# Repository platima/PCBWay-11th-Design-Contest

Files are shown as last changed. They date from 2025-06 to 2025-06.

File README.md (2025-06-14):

# Innovation Lightbulb Badge - Touch-Activated RGB LEDs

**🏆 My entry for the PCBWay 11th Design Contest:** *"11 Years of Innovation and Beyond with PCBWay"*


## Table of Contents
- [Overview](#overview)
- [Features](#-features)
- [Hardware Requirements](#-hardware-requirements)
- [Getting Started](#-getting-started)
  - [Prerequisites](#prerequisites)
  - [Assembly Instructions](#assembly-instructions)
  - [Programming Setup](#programming-setup)
  - [Installation](#installation)
- [How It Works](#-how-it-works)
- [Configuration](#️-configuration)
- [PCB Design](#-pcb-design)
- [Performance](#-performance)
- [Troubleshooting](#️-troubleshooting)
- [Animation Modes](#-animation-modes)
- [Power Management](#-power-management)
- [Future Enhancements](#-future-enhancements)
- [Version History](#-version-history)
- [Contributing](#-contributing)
- [License](#-license)
- [Acknowledgments](#-acknowledgments)
- [Contact](#-contact)

## Overview

A creative lightbulb-shaped badge featuring touch-activated LED animations, combining PCB art with functional electronics. The badge celebrates PCBWay's 11-year journey with an interactive cog/gear LED pattern that comes to life when you touch the golden snake base.

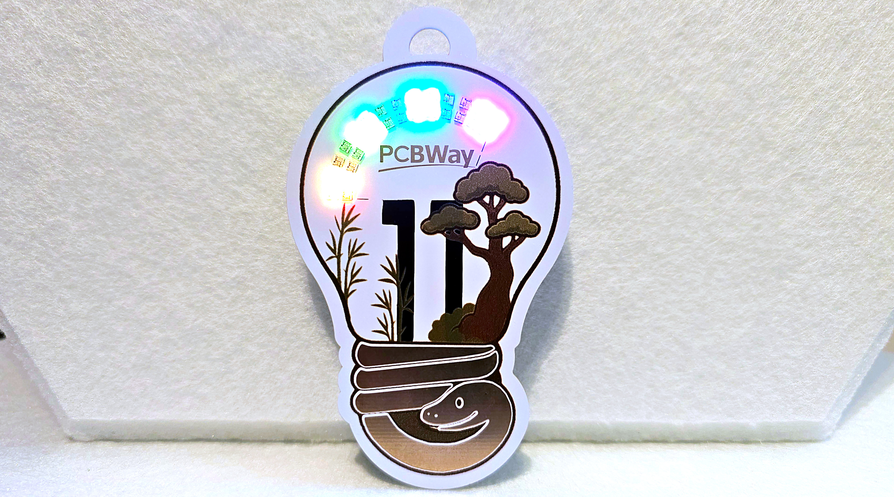
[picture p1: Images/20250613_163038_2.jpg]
Innovation Lightbulb Badge


*The completed Innovation Lightbulb Badge showcasing PCBWay's precision manufacturing. [Animation video here](https://youtu.be/jnBDUs-5CoI)*

## 🌟 Features

- **Touch Activation**: 28 cog/gear LEDs illuminate when touching the golden snake base
- **Multiple Animation Modes**: 5 different color patterns including rainbow, PCBWay green, fortune red, Australian colors, and white
- **Rotating Animation**: LED pattern simulates a turning gear/cog mechanism with configurable speed
- **Cultural Integration**: Year of the Wood Snake (2025) with bamboo and Chinese pine tree artwork
- **PCB Art**: Complex lightbulb cutout showcasing PCBWay's precision manufacturing and UV print capabilities
- **Low Power Design**: Battery-efficient with automatic sleep mode when not in use
- **Mode Cycling**: Automatically cycles through different color themes every 10 seconds of use
- **Interactive Badge**: Encourages human connection and conversation
- **Open Source**: Full KiCad files, firmware, and documentation shared with the maker community

## 🔧 Hardware Requirements

### Main Components
- **PCB**: Custom lightbulb-shaped design (order from PCBWay)
- **Microcontroller**: STM8S003F3P6 (20-pin TSSOP package)
- **LEDs**: 28x WS2812B addressable RGB LEDs (32 configured in firmware for animation wrapping)
- **Power**: LiPo battery (recommended: 503035 or 602535 with protection circuit)
- **Touch Sensor**: Golden snake pads (built into PCB design)

### Additional Components
See [/Hardware/BOM.csv](/Hardware/BOM.csv) for complete bill of materials including:
- Voltage regulators and power management ICs
- Capacitors and resistors
- Battery charging circuit components
- Programming header components

### Tools Required
- **Programming**: ST-Link v2 programmer (or compatible)
- **Soldering**: Hot air rework station, solder paste, flux
- **Assembly**: Fine-tip tweezers, magnifying glass
- **Power**: 3.3-5V power supply or LiPo battery

## 🚀 Getting Started

### Prerequisites

#### Software Requirements
- **Arduino IDE 2.0** or later
- **STM8 Arduino Core**: Add `https://github.com/akashkapashia/stm8_arduino/raw/master/package_sduino_stm8_index.json` to Board Manager URLs
- **ST-Link Drivers**: Install ST-Link v2 drivers for your operating system

#### Hardware Requirements
- ST-Link v2 programmer
- 4-wire connection: RST, GND, SWIM, 5V
- Power source (battery or bench supply)

### Assembly Instructions

#### Ordering PCB from PCBWay

##### Option 1 - KiCad Plugin (Recommended)
1. Download the complete `/Hardware/KiCad Files/` folder
2. Open `PCBWay_11th_Design_Contest.kicad_pro` in KiCad 9 or later
3. Use the PCBWay plugin to order directly from KiCad
4. Select UV printing option for the artwork layers

##### Option 2 - Manual Gerber Upload
1. Visit [PCBWay.com](https://www.pcbway.com)
2. Upload [/Hardware/Gerbers.zip](/Hardware/Gerbers.zip)
3. **Important**: Request UV printing for the artistic layers
4. Optional: Upload [/Hardware/BOM.csv](/Hardware/BOM.csv) and [/Hardware/Centroid.pos](/Hardware/Centroid.pos) for assembly service

##### Option 3 - Shared Project
Order from the [PCBWay Shared Projects Page](https://www.pcbway.com/project/shareproject/Innovation_Lightbulb_Badge_Touch_Activated_LED_Controller_d56364aa.html)

#### Soldering Process

**⚠️ Important Soldering Order:**
1. **Front LEDs First**: Apply solder paste and reflow the 28 WS2812B LEDs on the front
2. **Back SMD Components**: Apply solder paste and reflow all SMD components on the back
3. **Edge Components**: Use hot air gun for edge-mounted components (decoupling capacitors, if used)

#### Key Soldering Notes
- **LED Capacitors**: Optional but recommended for stable operation
- **R4 (0Ω Resistor)**: Can be used to force-enable LEDs for testing (bypasses touch sensor)
- **Programming Pads**: Ensure clean connections for reliable programming

### Programming Setup

#### Connection Diagram
```
ST-Link v2   →    Badge Programming Pads
-----------         ----------------------
/5V          →     5V  (marked with [])
GND          →     GND (marked with ())
SWIM         →     SWIM (marked with ())
NRST         →     RST (marked with ()))
```

#### Programming Pad Layout
```
Top of bulb shape

( ) RST    - Reset pin
( ) GND    - Ground
( ) SWIM   - Single Wire Interface Module
[ ] 5V     - Power supply (square pad)

Bottom of bulb / thread
```

### Installation

#### Method 1 - Arduino IDE (Recommended for Development)
1. **Clone the repository:**
   ```bash
   git clone https://github.com/platima/PCBWay-11th-Design-Contest.git
   cd PCBWay-11th-Design-Contest
   ```

2. **Install STM8 Arduino Core:**
   - Open Arduino IDE
   - Go to File → Preferences
   - Add board manager URL: `https://github.com/akashkapashia/stm8_arduino/raw/master/package_sduino_stm8_index.json`
   - Go to Tools → Board → Board Manager
   - Search for "STM8" and install the package

3. **Configure Board Settings:**
   - Board: "STM8S103F3"

4. **Upload Firmware:**
   - Open `Firmware/firmware.ino`
   - Connect ST-Link to programming pads (or hold in place)
   - Click Upload

#### Method 2 - Pre-compiled Hex File (Quick Start)
1. **Download and extract:** [firmware.ino.hex.zip](firmware.ino.hex.zip)
2. **Obtain stm8flash:** from https://github.com/vdudouyt/stm8flash
3. **Flash using stm8flash:**
   ```bash
   stm8flash -c stlinkv2 -p stm8s003f3 -w firmware.ino.hex
   ```

## 🎨 How It Works

### System Architecture

The badge operates in two distinct modes based on touch sensor input:

#### 1. Standby Mode (Power Saving)
- **All LEDs Off**: Conserves battery power
- **Touch Monitoring**: ADC continuously samples the golden snake pads
- **Low Power**: Minimal current draw for extended battery life
- **Wake-up Ready**: Instantly responds to touch detection (150ms)

#### 2. Active Mode (Animation Running)
- **Touch Detected**: ADC reading exceeds 800mV threshold
- **LED Animation**: Cog/gear pattern with rotating effect
- **Mode Cycling**: Automatically changes color themes every 10 seconds
- **Continuous Operation**: Runs until touch is no longer detected

#### 3. Touch Sensor Technology
- **Resistive Touch**: Uses skin conductivity to detect finger presence
- **Golden Snake Pads**: Artistic PCB traces serve as touch electrodes
- **ADC Monitoring**: STM8's built-in ADC on PD5 measures voltage changes
- **Threshold Detection**: 800mV threshold provides reliable touch detection

#### 4. LED Animation System
- **Cog/Gear Pattern**: 28 LEDs arranged in 14×2 tooth configuration
- **Rotating Effect**: Pattern shifts by 2 LEDs every 200ms
- **Color Modes**: 5 different themes with smooth transitions
- **Modular Design**: 32 LEDs configured in firmware for seamless wrapping

## ⚙️ Configuration

### Animation Timing
```c
#define ANIMATION_DELAY 200     // Animation speed (200ms = 5 FPS)
#define MODE_CHANGE_MS  10000   // Mode change interval (10 seconds)
```

### Cog Pattern Settings
```c
#define TOOTH_SIZE      4       // LEDs per color segment
#define TOOTH_GAP       4       // Gap between segments  
#define SHIFT_AMOUNT    2       // Animation shift speed (LEDs per frame)
#define N_LEDS          32      // Total LEDs (28 physical + 4 for wrapping)
```

### Touch Sensitivity
```c
#define TOUCH_THRESHOLD_MV 800  // Touch threshold (800mV)
#define ADC_VREF_MV     4100    // Reference voltage (4.1V)
#define ADC_RESOLUTION  1023    // 10-bit ADC resolution
```

### Visual Settings
```c
#define BRIGHTNESS      64      // LED brightness (0-255, set to 25%)
```

## 🎨 Animation Modes

The badge features 5 distinct animation modes that cycle automatically:



### 1. Rainbow Mode (`MODE_RAINBOW`) - Default
- **Colors**: Full spectrum rainbow cycling
- **Pattern**: Each LED position gets a different hue
- **Effect**: Creates a vibrant, eye-catching display
- **Use Case**: General demonstration and attraction

### 2. PCBWay Mode (`MODE_PCBWAY`)
- **Colors**: PCBWay signature green (RGB: 17, 167, 59)
- **Pattern**: Solid green cog rotation
- **Effect**: Brand-themed animation
- **Use Case**: PCBWay events and demonstrations

### 3. Fortune Mode (`MODE_FORTUNE`)
- **Colors**: Traditional Chinese red
- **Pattern**: Solid red cog rotation
- **Effect**: Cultural significance for good fortune
- **Use Case**: Chinese New Year, cultural events

### 4. Australia Mode (`MODE_AUSTRALIA`)
- **Colors**: Green and gold alternating
- **Pattern**: Alternating national colors
- **Effect**: Patriotic themed display
- **Use Case**: Australian events (customizable for other countries)

### 5. White Mode (`MODE_WHITE`)
- **Colors**: Pure white
- **Pattern**: Clean, bright white cog
- **Effect**: Professional, elegant appearance
- **Use Case**: Formal events, demonstrations

## ⚡ Power Management

### Battery Specifications
- **Recommended**: 503035 (500mAh) or 602535 (600mAh) LiPo
- **Voltage**: 3.7V nominal (3.0V - 4.2V range)
- **Protection**: Built-in PCM (Protection Circuit Module) required

### Power Consumption
- **Standby Mode**: <1mA (touch sensor monitoring only)
- **Active Mode**: ~200mA (all LEDs at 25% brightness)
- **Battery Life**: 
  - Standby: Several days
  - Continuous use: 2-3 hours
  - Typical use (intermittent): 8-12 hours

### Charging
- Use external charger such as [LiPo Charger Module (Basic)](https://shop.plati.ma/products/lipo-charger-module)

## 🔨 PCB Design

### Design Features
- **Artistic Shape**: Lightbulb cutout showcasing PCB manufacturing precision
- **LED Layout**: 28 WS2812B LEDs arranged in perfect cog/gear pattern
- **Touch Pads**: Golden snake design serves as capacitive touch sensor
- **Cultural Elements**: Year of the Wood Snake 2025 artwork
- **Functional Art**: UV printing demonstrates PCBWay's advanced capabilities

### Technical Specifications
- **Dimensions**: 58.74mm wide, 98.5mm tall
- **Layers**: 2-layer PCB with artistic copper pours
- **Thickness**: 1.2-1.6mm standard PCB thickness (FR4)
- **Surface Finish**: ENIG for golden appearance, else HASL
- **UV Printing**: Multi-color artwork on solder mask

### Programming Interface
- **Connector**: 4-pin programming header
- **Layout**: RST, GND, SWIM, 5V
- **Access**: Easily accessible on PCB back
- **Protection**: Test points for reliable connection

## 📈 Performance

### Response Characteristics
- **Touch Response**: <50ms from touch to LED activation
- **Animation Frame Rate**: 5 FPS (200ms per frame)
- **Color Accuracy**: 24-bit RGB with gamma correction
- **Power Efficiency**: >99% idle time power savings

### Environmental Specifications
- **Operating Temperature**: -10°C to +60°C
- **Storage Temperature**: -20°C to +80°C
- **Humidity**: 0-95% non-condensing
- **Vibration**: Suitable for badge/wearable use

### Recommendations
- **Battery**: Use velcro or similar adhesive to attach LiPo to back of PCB 

## 🛠️ Troubleshooting

### LED Issues

**Problem**: LEDs don't light up
**Solutions**:
- Check power supply voltage (minimum 3.5V for WS2812B)
- Verify solder connections on data line (PD4)
- Test with multimeter: 5V, GND, and data signal
- Ensure correct LED orientation (check datasheet pin 1)

**Problem**: Some LEDs don't work
**Solutions**:
- Check for cold solder joints on faulty LEDs
- Verify data chain continuity (WS2812B are daisy-chained)
- Test individual LED with reduced brightness
- Replace faulty LEDs if necessary

### Touch Sensor Issues

**Problem**: Touch sensor not responding
**Solutions**:
- Verify ADC configuration and PD5 connection
- Check threshold setting (try lowering `TOUCH_THRESHOLD_MV`)
- Clean golden snake pads (remove oxidation/contamination)
- Test with multimeter: voltage should change when touched
- Populate R4 (0Ω) to bypass touch sensor for testing

**Problem**: Touch sensor too sensitive
**Solutions**:
- Increase `TOUCH_THRESHOLD_MV` value
- Check for electrical noise affecting ADC
- Ensure proper grounding of the badge
- Add filtering capacitor if needed

### Programming Issues

**Problem**: Cannot program STM8
**Solutions**:
- Verify ST-Link connections (RST, GND, SWIM, 5V)
- Check ST-Link driver installation
- Ensure 5V power supply to badge during programming
- Try different programming cable/connection
- Reset STM8 before programming attempt

**Problem**: Code compiles but doesn't run
**Solutions**:
- Verify clock configuration (16MHz HSI)
- Check for infinite loops in initialization
- Add debug outputs to identify where code stops
- Verify all peripheral configurations

### Animation Issues

**Problem**: Animation stuttering or irregular
**Solutions**:
- Reduce `ANIMATION_DELAY` for smoother motion
- Check power supply stability (use oscilloscope)
- Verify timing calculations in animation code
- Ensure adequate power supply current capability

**Problem**: Wrong colors or color order
**Solutions**:
- Verify `COLOR_ORDER` setting (should be `grb` for WS2812B)
- Check LED manufacturer specifications
- Test with simple solid colors first
- Verify RGB color calculations in mode functions

## 🚧 Future Enhancements

### Community Contributions
- [ ] **Pattern Library**: User-submitted animation patterns
- [ ] **3D Printed Case**: Protective housing with lanyard attachment
- [ ] **Alternative Themes**: Country-specific color schemes
- [ ] **Educational Modules**: Programming tutorials and exercises
- [ ] **Hardware Variants**: Different LED counts and arrangements

### Advanced Features
- [ ] **Battery Monitoring**: Visual battery level indication
- [ ] **Event Modes**: Special patterns for holidays and events
- [ ] **Diagnostic Mode**: Self-test and troubleshooting features

## 📋 Version History

### Version 3.0 (Current - June 2025)
- ✅ Touch sensor functionality with ADC-based detection
- ✅ Five animation modes with automatic cycling
- ✅ Low-power sleep mode implementation
- ✅ Optimized cog/gear animation with smooth rotation
- ✅ Battery-efficient operation with wake-on-touch
- ✅ Complete STM8 Arduino IDE integration

### Version 2.0 (Development)
- ✅ STM8 microcontroller port completion
- ✅ WS2812B LED driver optimization
- ✅ Basic animation patterns implementation
- ✅ PCB design refinement and testing

### Version 1.0 (Prototype)
- ✅ Initial WS2812 control implementation
- ✅ Basic LED functions and color control
- ✅ Proof-of-concept hardware design

## 🤝 Contributing

This project is part of the PCBWay 11th Design Contest and is open source for the maker community!

### How to Contribute
1. **Fork the repository** on GitHub
2. **Create a feature branch** (`git checkout -b feature/amazing-feature`)
3. **Make your changes** with clear commit messages
4. **Test thoroughly** on actual hardware if possible
5. **Submit a pull request** with detailed description

### Contribution Guidelines
- **Code Style**: Follow existing Arduino/C++ conventions
- **Documentation**: Update README and code comments
- **Testing**: Verify changes don't break existing functionality
- **Hardware**: Test on actual badge hardware when possible

### Areas for Contribution
- **New Animation Modes**: Creative LED patterns and effects
- **Power Optimization**: Extend battery life further
- **Code Optimization**: Improve performance and memory usage
- **Documentation**: Tutorials, guides, and examples
- **Hardware Variants**: Alternative designs and improvements

## 📄 License

This project is licensed under the MIT License - see the [LICENSE](LICENSE) file for details.

### License Summary
- ✅ Commercial use permitted
- ✅ Modification and distribution allowed
- ✅ Private use encouraged
- ❌ No warranty provided
- 📝 License and copyright notice required

## 🙏 Acknowledgments

### Special Thanks
- **PCBWay** for hosting the 11th Design Contest and providing exceptional PCB manufacturing services
- **akashkapashia** for maintaining and improving the STM8 Arduino core library
- **ctxz** for the excellent TinyWS2812 library that makes WS2812B control seamless
- **STMicroelectronics** for the robust and affordable STM8 microcontroller platform
- **Adafruit** for pioneering WS2812 integration and providing extensive documentation
- **Wifey** for her patience with my stress, design and symbolism input, and feedback

### Community Support
- **EEVblog Forum** for embedded systems design discussions
- **Arduino Community** for programming support and examples  
- **KiCad Community** for PCB design tools and libraries
- **GitHub Contributors** for code reviews and improvements
- **Maker Community** for inspiration and creative ideas

### Technical Resources
- **STM8 Reference Manual** for comprehensive hardware documentation
- **WS2812B Datasheet** for LED timing and electrical specifications
- **PCB Manufacturing Guidelines** from PCBWay for design optimization
- **Embedded Systems Tutorials** for low-power design techniques

## 📞 Contact

### Project Information
- **GitHub Repository**: [PCBWay-11th-Design-Contest](https://github.com/platima/PCBWay-11th-Design-Contest)
- **Author**: [@platima](https://github.com/platima) (PlatimaTinkers)
- **Contest**: PCBWay 11th Badge Design Contest 2025
- **Theme**: "11 Years of Innovation and Beyond with PCBWay"

### Support and Questions
- **Issues**: [GitHub Issues](https://github.com/platima/PCBWay-11th-Design-Contest/issues)
- **Discussions**: [GitHub Discussions](https://github.com/platima/PCBWay-11th-Design-Contest/discussions)
- **Email**: [Contact through GitHub profile]

### Related Links
- **PCBWay Contest**: [Official Contest Page](https://www.pcbway.com/blog/News/PCBWay_11th_Badge_Design_Contest_7ac30a70.html)
- **PCBWay Shared Project**: [Direct Order Link](https://www.pcbway.com/project/shareproject/Innovation_Lightbulb_Badge_Touch_Activated_LED_Controller_d56364aa.html)
- **STM8 Arduino Core**: [akashkapashia/stm8_arduino](https://github.com/akashkapashia/stm8_arduino)
- **TinyWS2812 Library**: [ctxz/TinyWS2812](https://github.com/ctxz/TinyWS2812)

---

**🏆 PCBWay 11th Design Contest Entry**

*Showcasing innovative PCB design with practical embedded systems implementation*

**🐍 Year of the Wood Snake 2025** - *Celebrating innovation, creativity, and the maker spirit*

#Platima #NeoPixel #WS2812 #STM8 #Maker #Arduino #PCBWay #PCBWay11BadgeContest

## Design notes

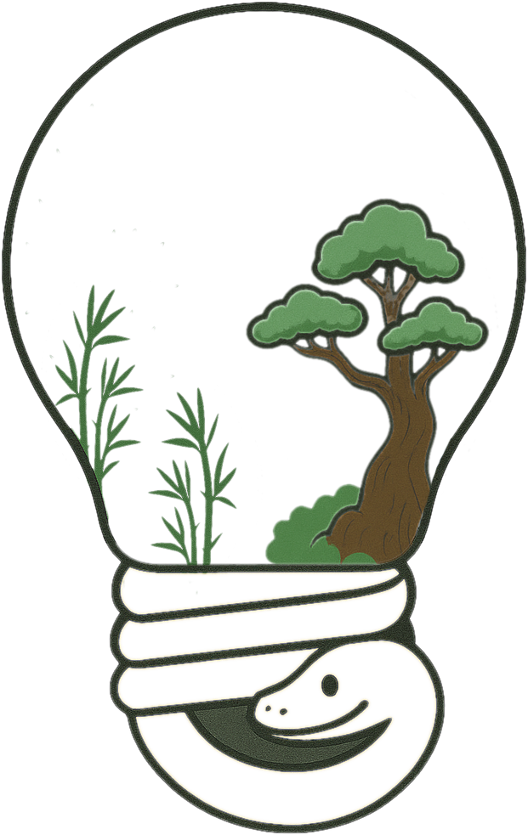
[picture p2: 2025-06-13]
Hardware/UV Layer.png

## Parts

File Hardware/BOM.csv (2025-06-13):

Id | Designator | Footprint | Quantity | Designation | Purchase Page
1 | D5,D23,D20,D18,D12,D25,D7,D1,D13,D6,D10,D3,D4,D26,D22,D17,D11,D9,D14,D2,D27,D19,D28,D21,D16,D15,D24,D8 | LED_XL-2020RGBC-WS2812B_Innerdot | 28 | XL-2020RGBC-WS2812B | https://www.digikey.com.au/en/products/detail/xinglight/xl-2020rgbc-ws2812b/25672933
2 | H1 | CONN-SMD_2P-P2.00_XUNPU_WAFER-PH2.0-2PWB | 1 | WAFER-PH2.0-2PWB | https://www.digikey.com.au/en/products/detail/jst-sales-america-inc/S2B-PH-SM4-TB/926655
3 | C14,C1,C11,C10,C9,C12,C13,C4 | C_0603_1608Metric | 8 | 100nF | https://www.mouser.com/ProductDetail/KYOCERA-AVX/06033G104ZAT2A
4 | IC1 | SOP65P640X120-20N | 1 | STM8S003F3P6 | https://www.mouser.com/ProductDetail/STMicroelectronics/STM8S003F3P6?qs=vV0pr1uq7fD%252BGii5YhjnYw%3D%3D
6 | R2 | R_0805_2012Metric | 1 | 10kOhm | https://www.mouser.com/ProductDetail/Royalohm/0805W8J0103T5E
7 | R1 | R_0805_2012Metric | 1 | 330Ohm | https://www.mouser.com/ProductDetail/Royalohm/0805W8J0331T5E
8 | C2 | C_0603_1608Metric | 1 | 10uF | https://www.mouser.com/ProductDetail/Samsung-Electro-Mechanics/CL10A106MQ8NNNC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
9 | C5 | C_0603_1608Metric | 1 | 1uF | https://www.mouser.com/ProductDetail/TAIYO-YUDEN/LMK107B7105MA-T
10 | R3 | R_0603_1608Metric | 1 | 100kOhm | https://www.mouser.com/ProductDetail/Royalohm/0603SAF1003T5E

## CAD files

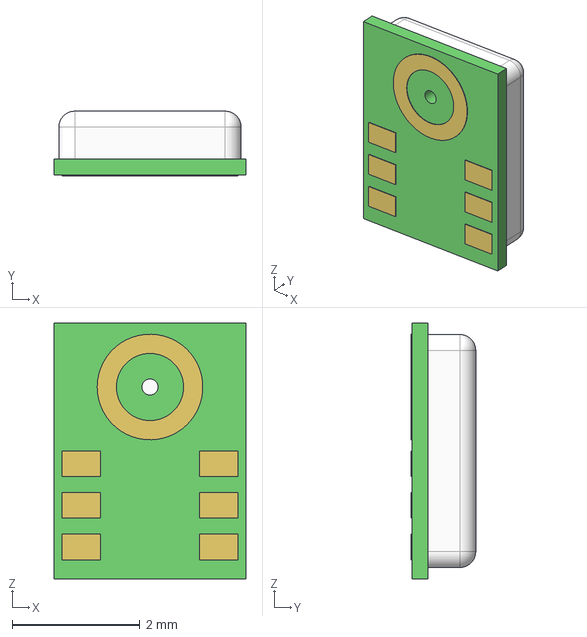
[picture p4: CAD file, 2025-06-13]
Hardware/KiCad Files/Models/DMM-4026-B-I2S-R.step
3.00 x 1.01 x 4.00 mm

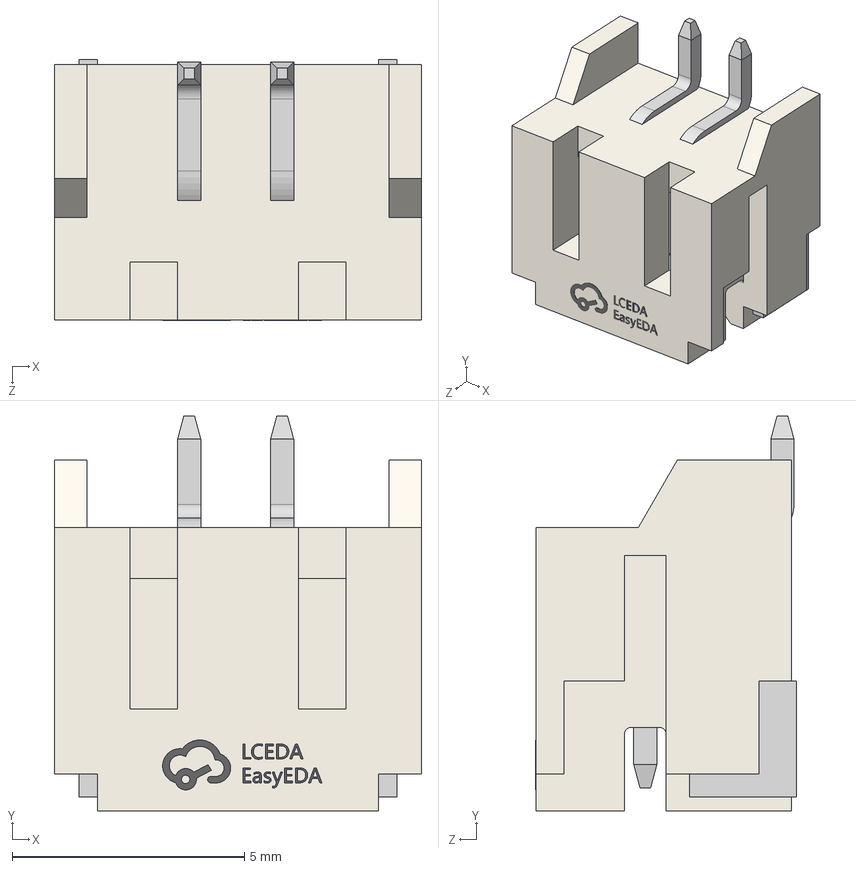
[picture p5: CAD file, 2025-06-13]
Hardware/KiCad Files/Models/CONN-SMD_2P-P2.00_XUNPU_WAFER-PH2.0-2PWB.step
7.90 x 8.50 x 5.61 mm

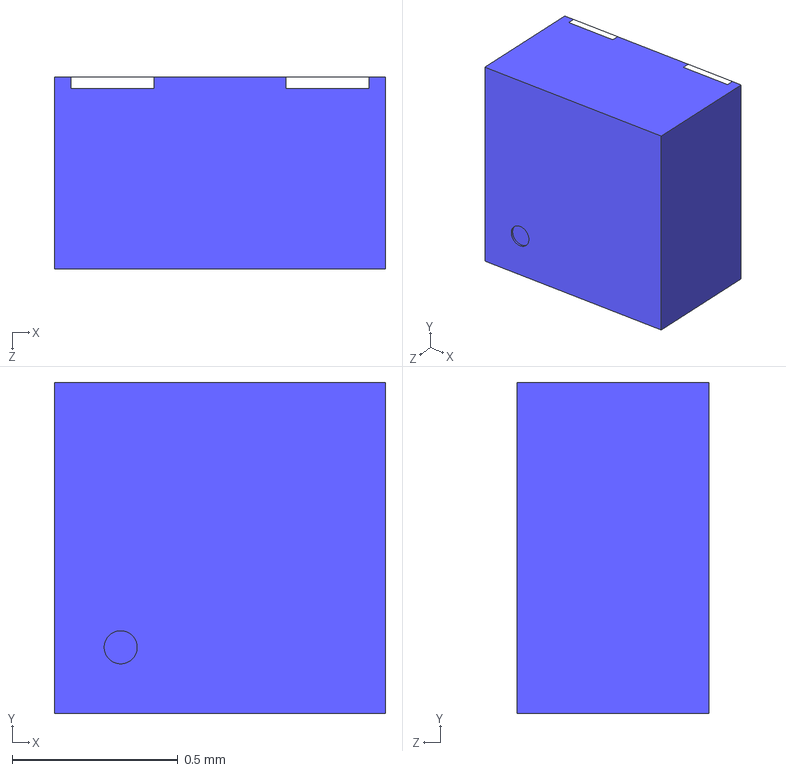
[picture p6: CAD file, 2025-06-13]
Hardware/KiCad Files/Models/TCR2EF50,LM_CT.stp
1.00 x 1.00 x 0.58 mm

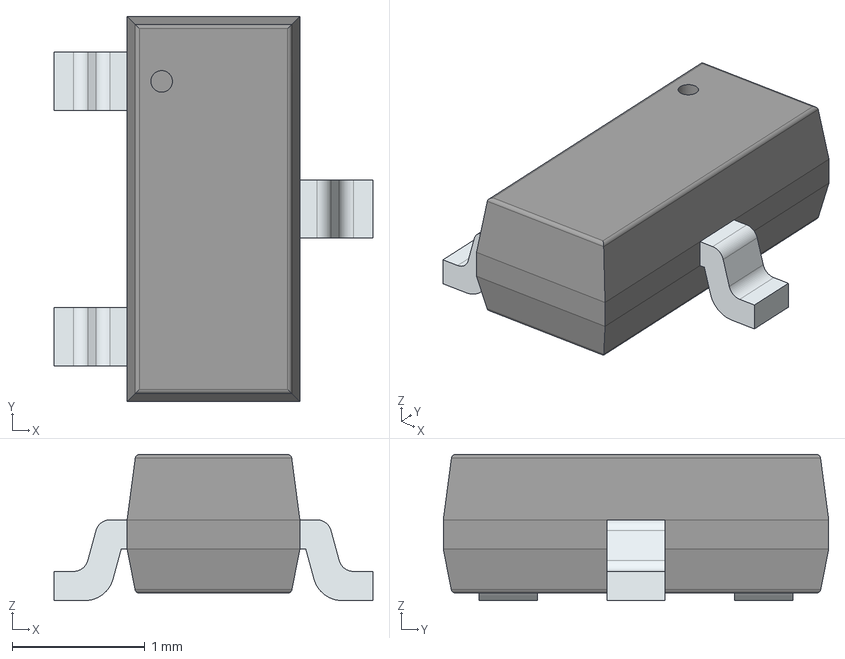
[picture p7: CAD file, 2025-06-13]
Hardware/KiCad Files/Models/FMMT491TA.stp
2.40 x 2.90 x 1.10 mm
PinsArrayL
FilletPinR

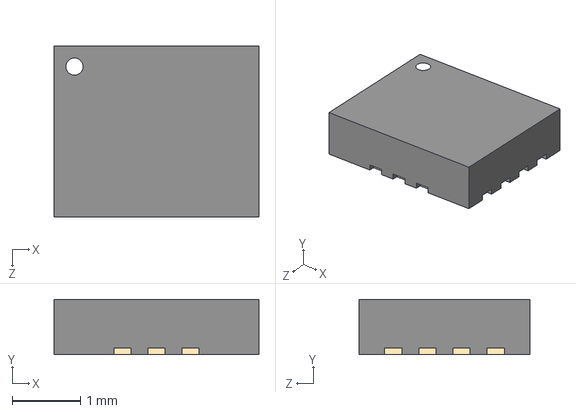
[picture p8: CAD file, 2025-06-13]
Hardware/KiCad Files/Models/ICM-42370-P.step
3.00 x 0.81 x 2.50 mm

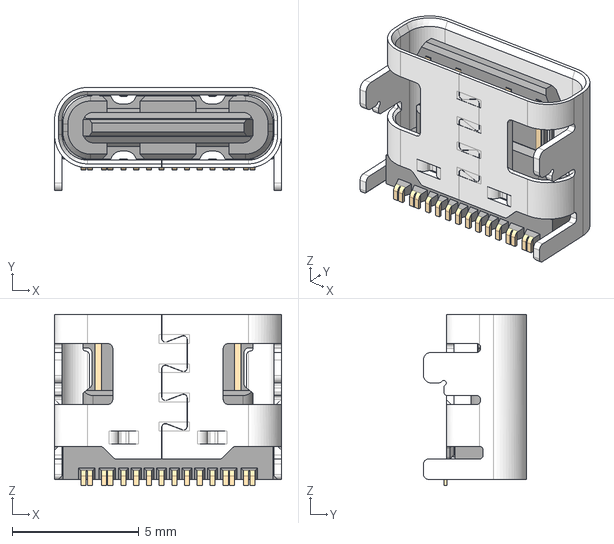
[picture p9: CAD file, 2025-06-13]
Hardware/KiCad Files/Models/usb4215-03-a.stp
8.94 x 4.06 x 6.75 mm

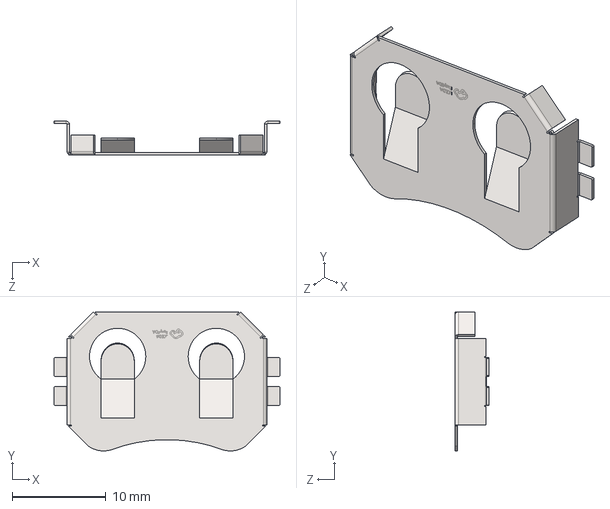
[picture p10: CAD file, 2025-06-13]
Hardware/KiCad Files/Models/BAT-SMD_MY-2032-12.step
24.1 x 14.8 x 3.61 mm

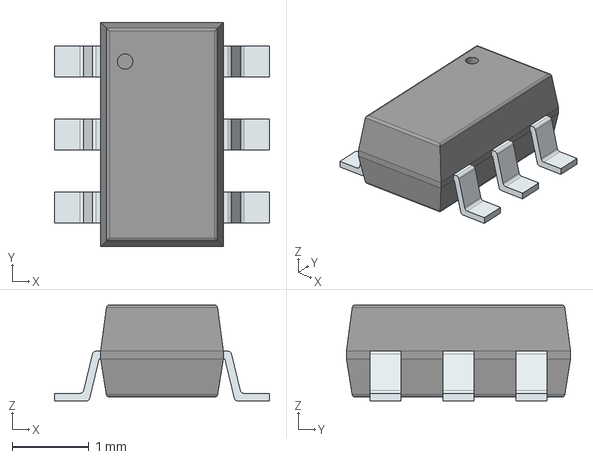
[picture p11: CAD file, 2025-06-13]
Hardware/KiCad Files/Models/FS8205A.stp
2.80 x 2.92 x 1.25 mm
PinsArrayLR

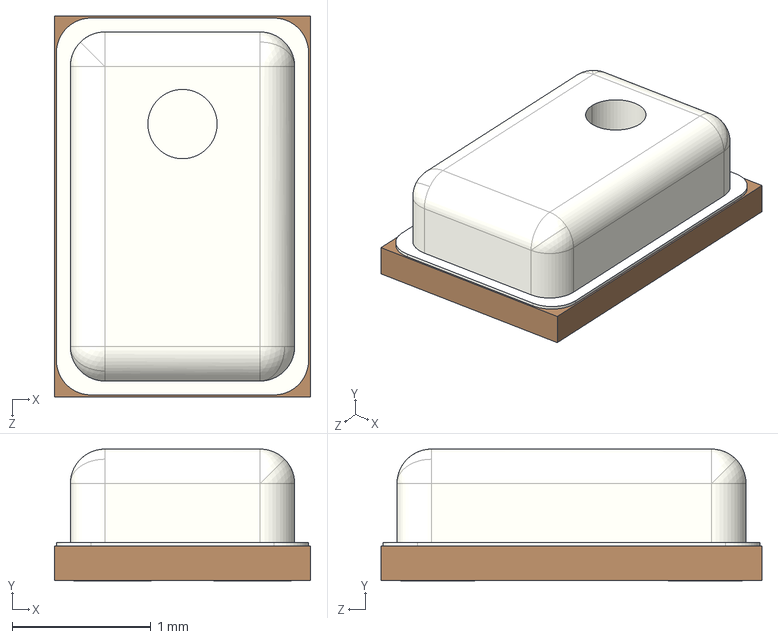
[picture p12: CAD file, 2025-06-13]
Hardware/KiCad Files/Models/CMM-2718AT-42316-TR.stp
1.85 x 0.952 x 2.75 mm

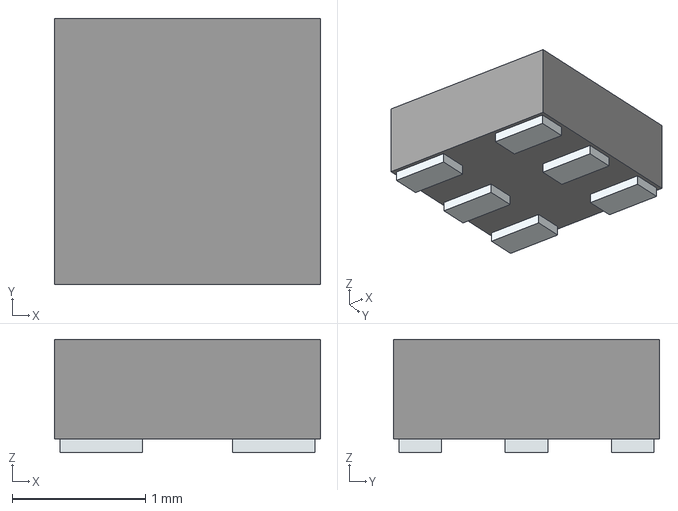
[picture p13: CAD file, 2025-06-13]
Hardware/KiCad Files/Models/XINGLIGHT-XL-2020RGBC-WS2812B.stp
2.00 x 2.00 x 0.85 mm
Pins

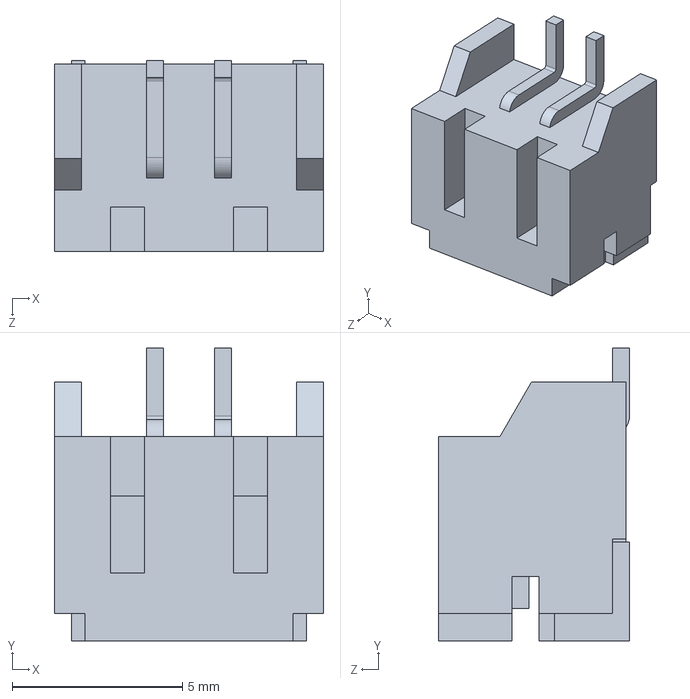
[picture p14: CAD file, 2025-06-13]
Hardware/KiCad Files/Models/S2B-PH-SM4-TB_LF__SN_.stp
7.90 x 8.60 x 5.60 mm

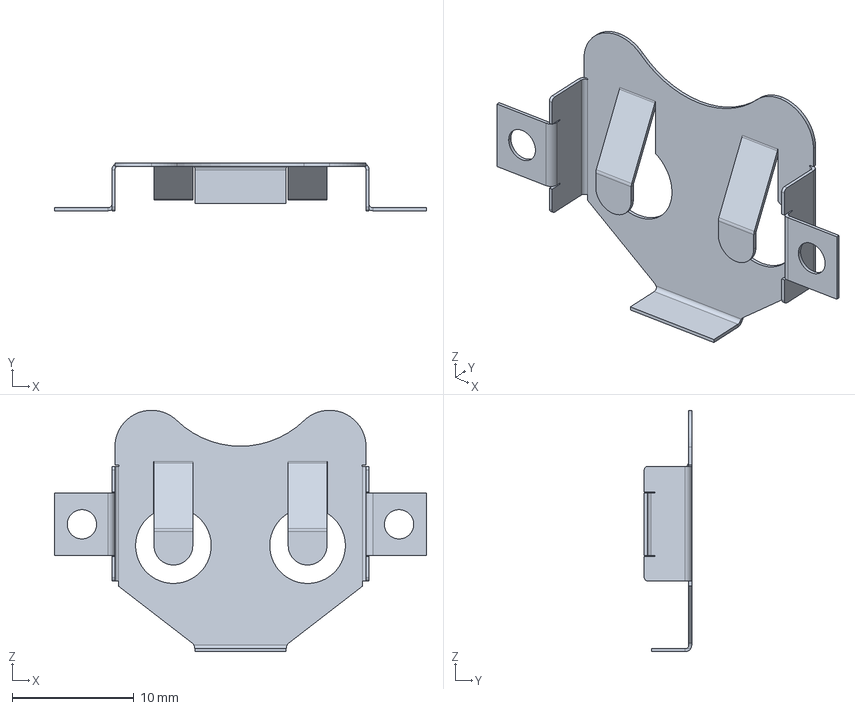
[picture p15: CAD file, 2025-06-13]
Hardware/KiCad Files/Models/BAT-HLD-003-SMT.stp
30.5 x 3.90 x 19.8 mm

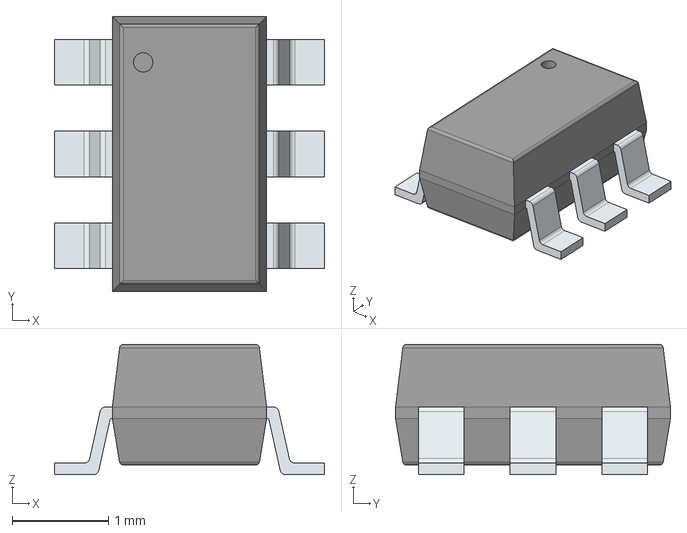
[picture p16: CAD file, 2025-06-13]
Hardware/KiCad Files/Models/DW01A-G.stp
2.80 x 2.85 x 1.35 mm
PinsArrayLR

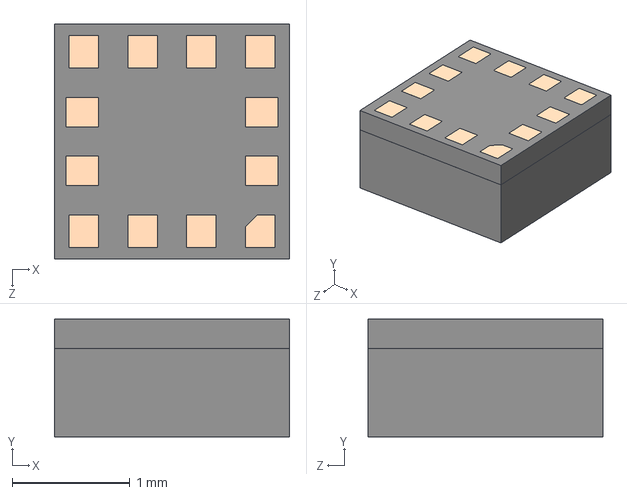
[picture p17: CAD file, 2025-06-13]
Hardware/KiCad Files/Models/LIS2DW12TR.stp
2.00 x 1.00 x 2.00 mm

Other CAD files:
Hardware/KiCad Files/Models/STM8S003F3P6.stp
Hardware/KiCad Files/Models/DMG2305UX-7.stp
Hardware/KiCad Files/Models/AT42QT1010-TSHR.stp
Hardware/KiCad Files/Models/TLV77333PDBVR.stp

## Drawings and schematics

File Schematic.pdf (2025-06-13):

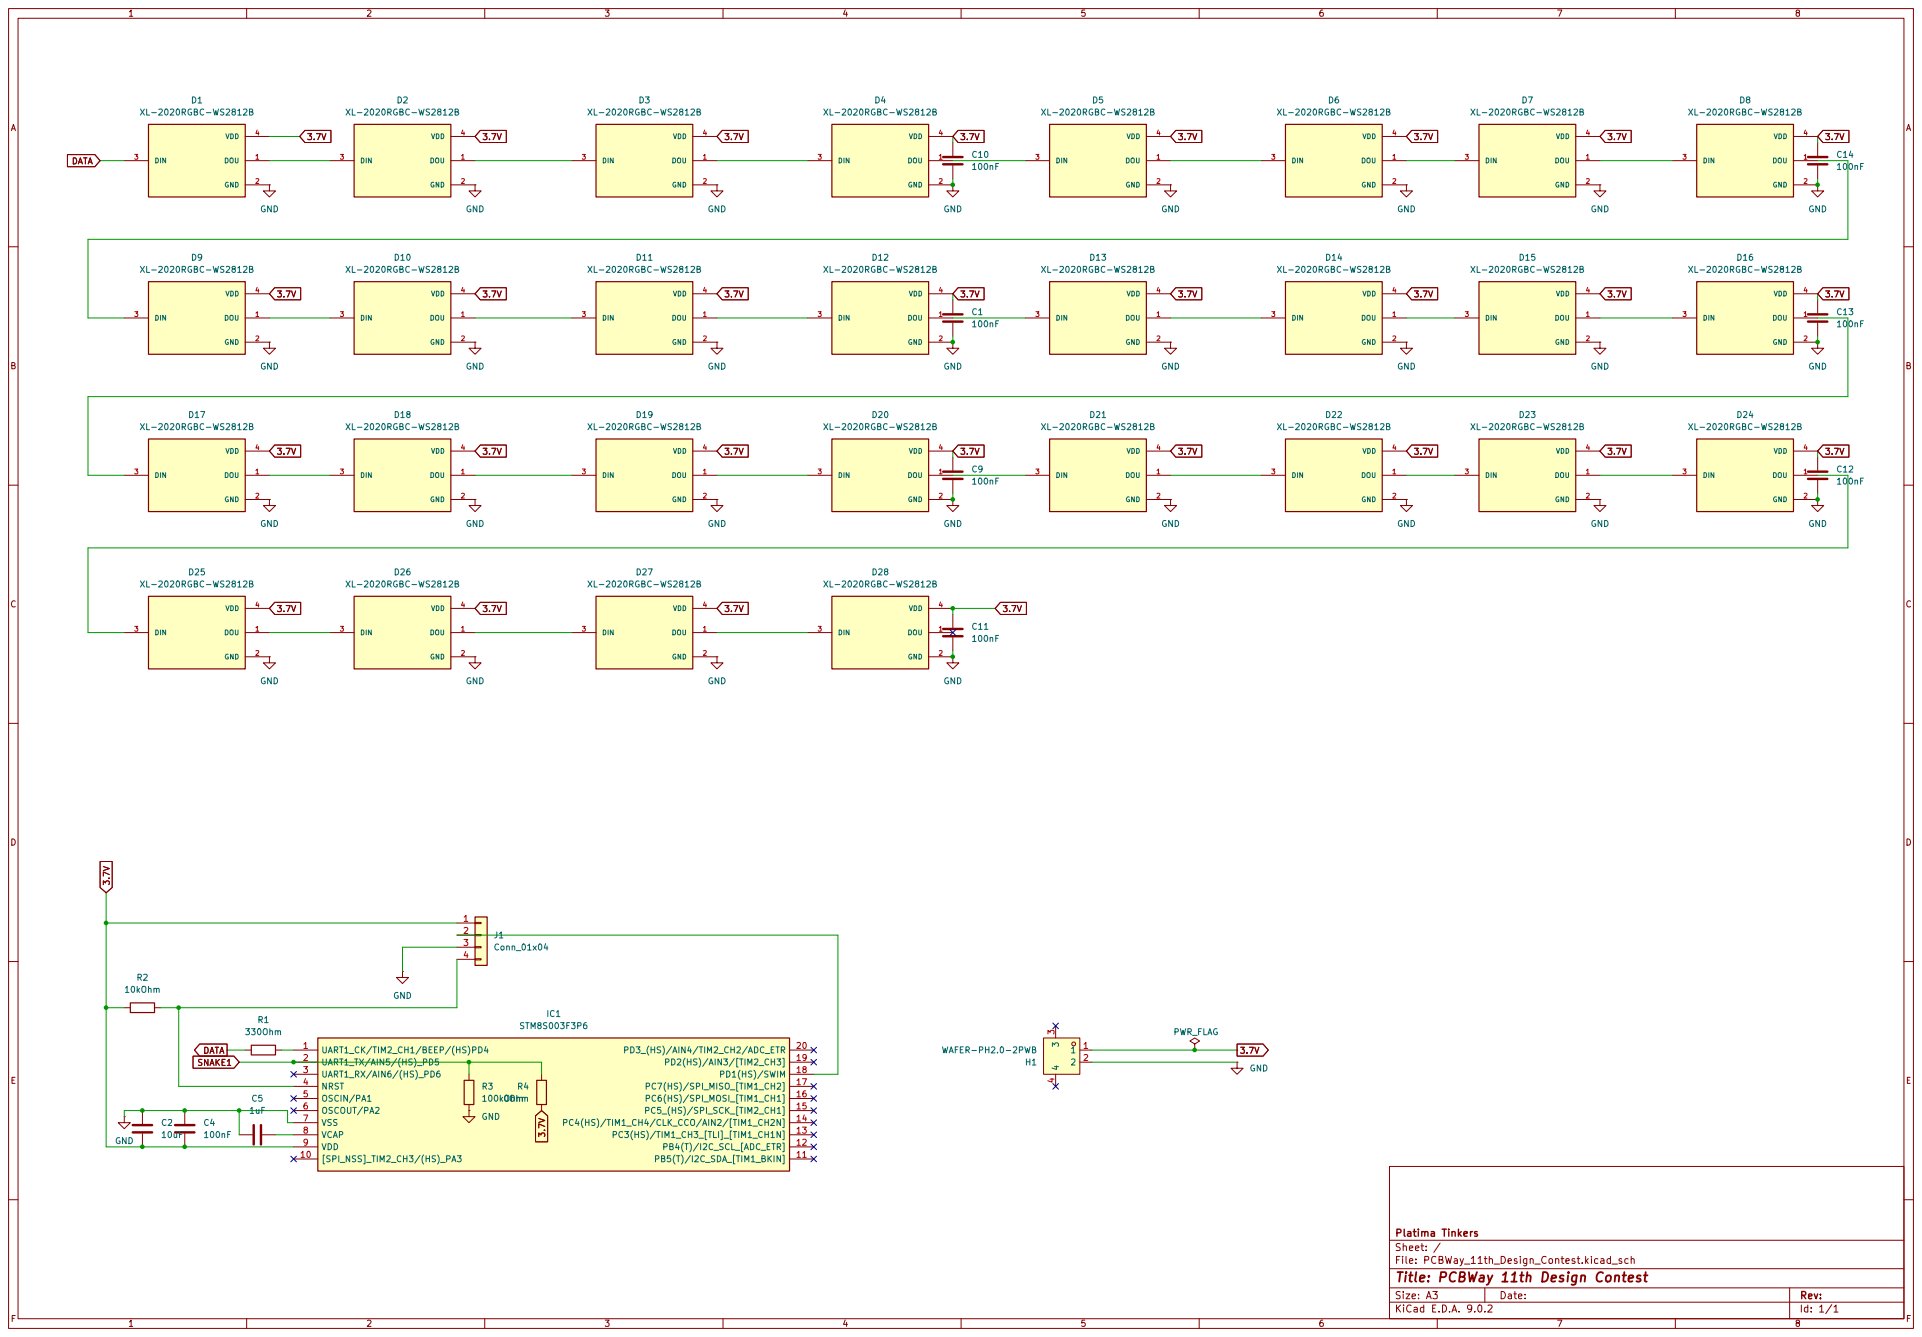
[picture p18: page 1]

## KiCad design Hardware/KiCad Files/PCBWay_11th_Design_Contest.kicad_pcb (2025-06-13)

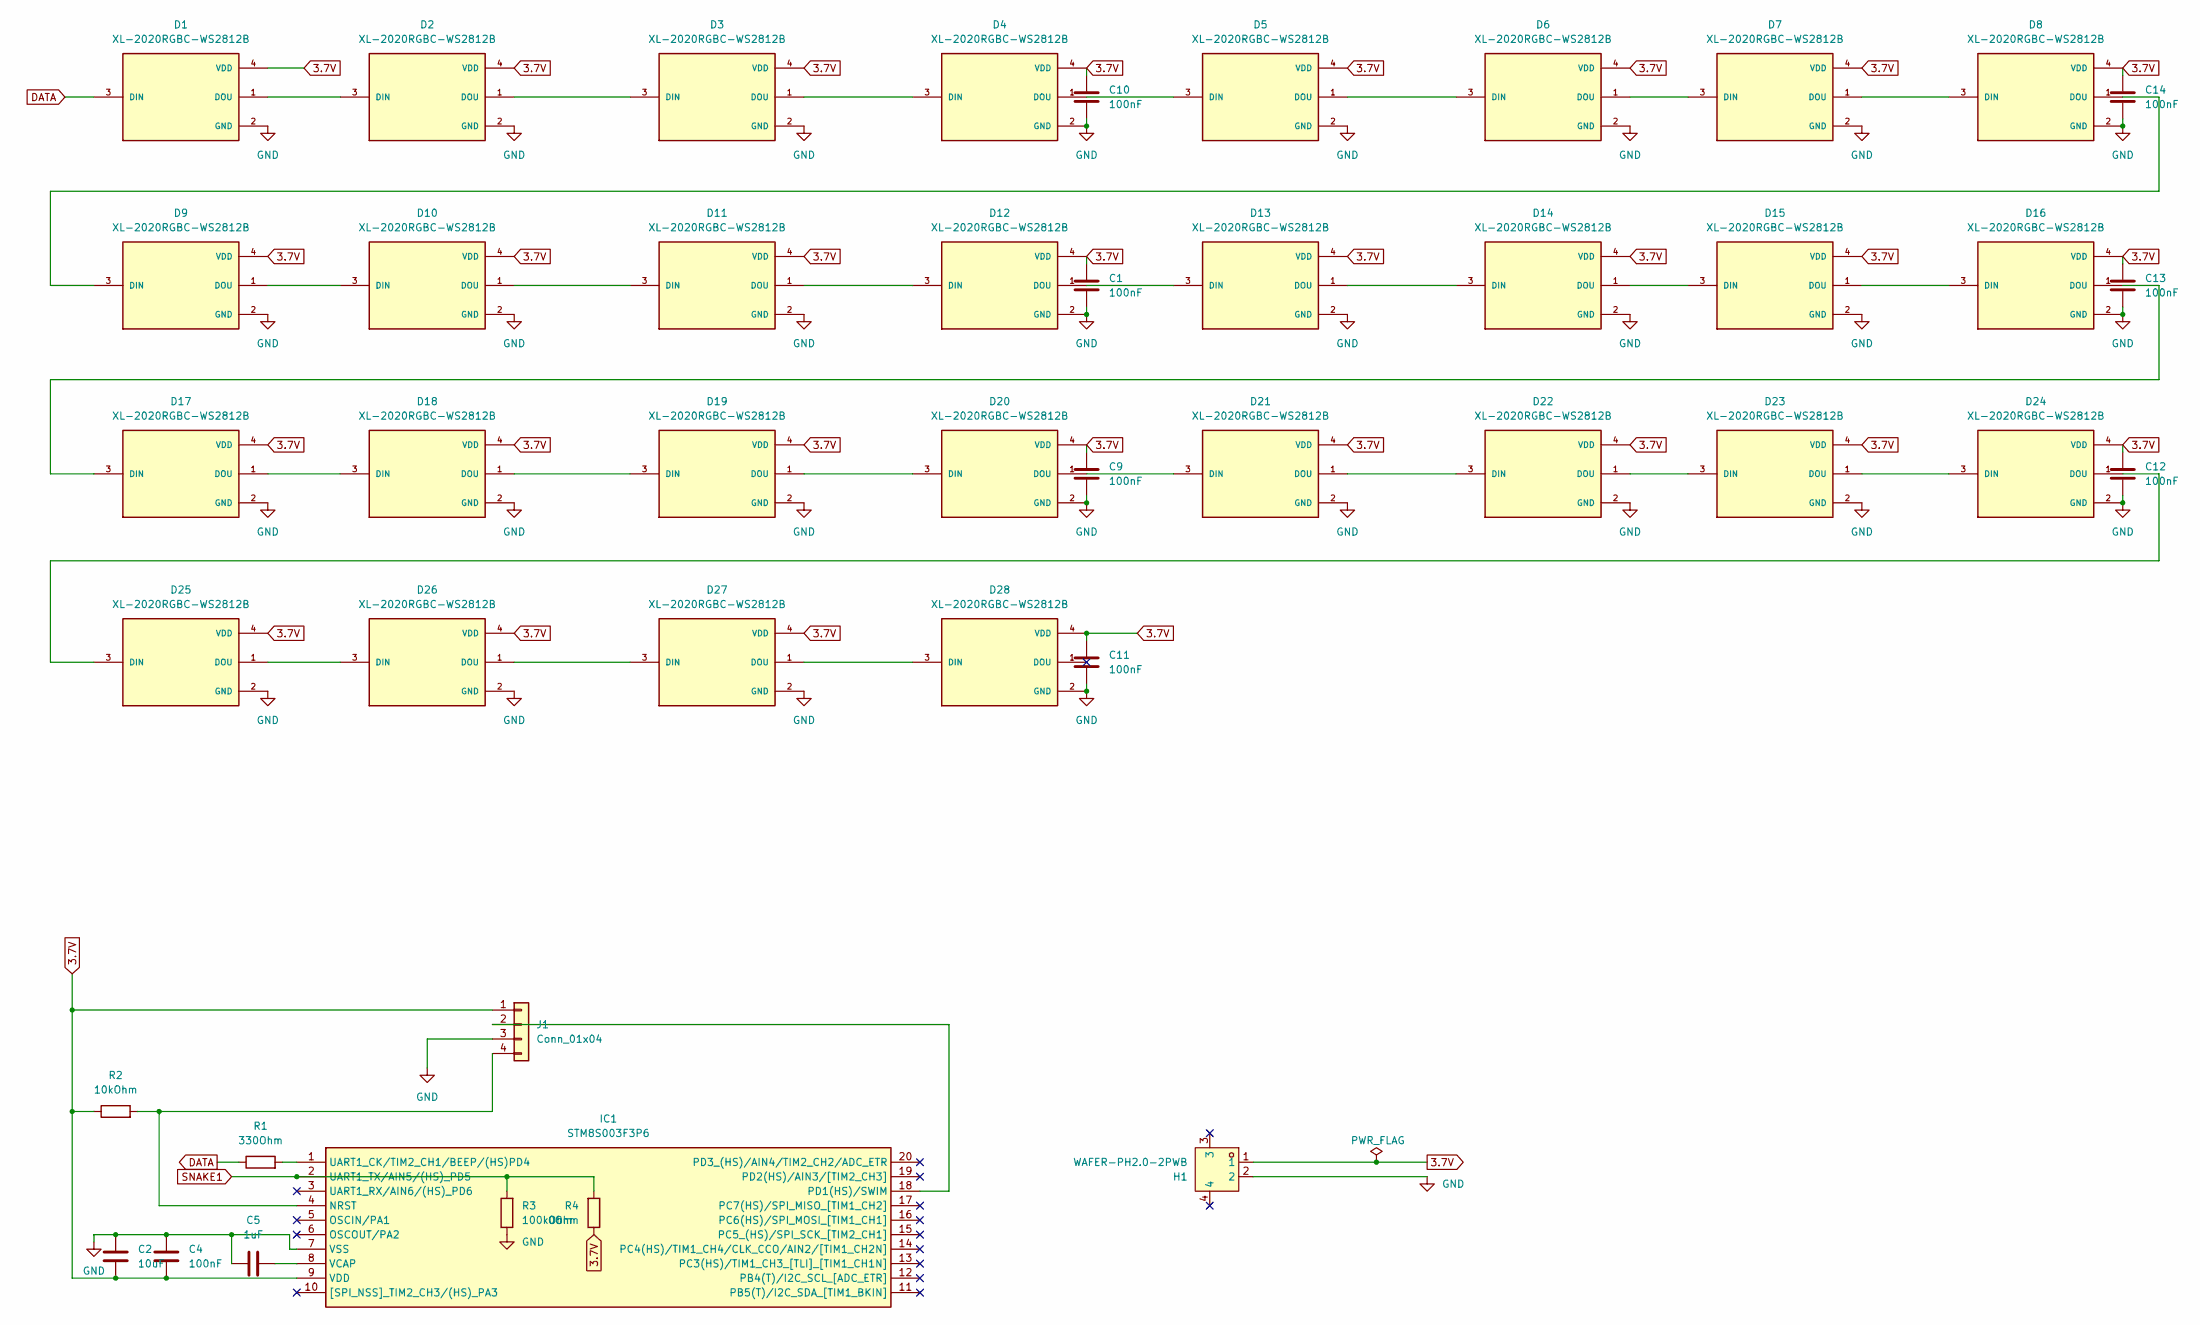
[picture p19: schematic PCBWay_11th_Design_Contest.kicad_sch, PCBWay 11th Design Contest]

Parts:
C1, C4, C9, C10, C11, C12, C13, C14: 100nF; C_0603_1608Metric; Part 0603B104K500NT
C2: 10uF; C_0603_1608Metric; Part GRM188R6YA106MA73D
C5: 1uF; C_0603_1608Metric; Part 0603B105M250NT
D1, D2, D3, D4, D5, D6, D7, D8, D9, D10, D11, D12, D13, D14, D15, D16, D17, D18, D19, D20, D21, D22, D23, D24, D25, D26, D27, D28: XL-2020RGBC-WS2812B; LED_XL-2020RGBC-WS2812B; PARTREV NA
H1: WAFER-PH2.0-2PWB; CONN-SMD_2P-P2.00_XUNPU_WAFER-PH2.0-2PWB; LCSC Part C3029440
IC1: STM8S003F3P6; SOP65P640X120-20N; Mouser Part Number 511-STM8S003F3P6
J1: Conn_01x04; PinHeader_1x04_P2.54mm_Vertical
R1: 330Ohm; R_0805_2012Metric; Part 0805W8J0331T5E
R2: 10kOhm; R_0805_2012Metric; Part 0805W8J0103T5E
R3: 100kOhm; R_0603_1608Metric; Part FRC0603F1003TS
R4: 0Ohm; R_0603_1608Metric

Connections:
3.7V: C1.1, C2.2, C4.2, C9.1, C10.1, C11.1, C12.1, C13.1, C14.1, D1.4 (VDD), D2.4 (VDD), D3.4 (VDD), D4.4 (VDD), D5.4 (VDD), D6.4 (VDD), D7.4 (VDD), D8.4 (VDD), D9.4 (VDD), D10.4 (VDD), D11.4 (VDD), D12.4 (VDD), D13.4 (VDD), D14.4 (VDD), D15.4 (VDD), D16.4 (VDD), D17.4 (VDD), D18.4 (VDD), D19.4 (VDD), D20.4 (VDD), D21.4 (VDD), D22.4 (VDD), D23.4 (VDD), D24.4 (VDD), D25.4 (VDD), D26.4 (VDD), D27.4 (VDD), D28.4 (VDD), H1.1, IC1.9 (VDD), J1.1, R2.1, R4.1
DATA: D1.3 (DIN), R1.1
GND: C1.2, C2.1, C4.1, C5.1, C9.2, C10.2, C11.2, C12.2, C13.2, C14.2, D1.2 (GND), D2.2 (GND), D3.2 (GND), D4.2 (GND), D5.2 (GND), D6.2 (GND), D7.2 (GND), D8.2 (GND), D9.2 (GND), D10.2 (GND), D11.2 (GND), D12.2 (GND), D13.2 (GND), D14.2 (GND), D15.2 (GND), D16.2 (GND), D17.2 (GND), D18.2 (GND), D19.2 (GND), D20.2 (GND), D21.2 (GND), D22.2 (GND), D23.2 (GND), D24.2 (GND), D25.2 (GND), D26.2 (GND), D27.2 (GND), D28.2 (GND), H1.2, IC1.7 (VSS), J1.3, R3.1
unnamed: D1.1 (DOU), D2.3 (DIN)
unnamed: D2.1 (DOU), D3.3 (DIN)
unnamed: D3.1 (DOU), D4.3 (DIN)
unnamed: D4.1 (DOU), D5.3 (DIN)
unnamed: D5.1 (DOU), D6.3 (DIN)
unnamed: D6.1 (DOU), D7.3 (DIN)
unnamed: D7.1 (DOU), D8.3 (DIN)
unnamed: D8.1 (DOU), D9.3 (DIN)
unnamed: D9.1 (DOU), D10.3 (DIN)
unnamed: D10.1 (DOU), D11.3 (DIN)
unnamed: D11.1 (DOU), D12.3 (DIN)
unnamed: D12.1 (DOU), D13.3 (DIN)
unnamed: D13.1 (DOU), D14.3 (DIN)
unnamed: D14.1 (DOU), D15.3 (DIN)
unnamed: D15.1 (DOU), D16.3 (DIN)
unnamed: D16.1 (DOU), D17.3 (DIN)
unnamed: D17.1 (DOU), D18.3 (DIN)
unnamed: D18.1 (DOU), D19.3 (DIN)
unnamed: D19.1 (DOU), D20.3 (DIN)
unnamed: D20.1 (DOU), D21.3 (DIN)
unnamed: D21.1 (DOU), D22.3 (DIN)
unnamed: D22.1 (DOU), D23.3 (DIN)
unnamed: D23.1 (DOU), D24.3 (DIN)
unnamed: D24.1 (DOU), D25.3 (DIN)
unnamed: D25.1 (DOU), D26.3 (DIN)
unnamed: D26.1 (DOU), D27.3 (DIN)
unnamed: D27.1 (DOU), D28.3 (DIN)
unnamed: IC1.4 (NRST), J1.4, R2.2
unnamed: IC1.18 (PD1(HS)/SWIM), J1.2
unnamed: IC1.1 (UART1_CK/TIM2_CH1/BEEP/(HS)PD4), R1.2
unnamed: C5.2, IC1.8 (VCAP)
SNAKE1: IC1.2 (UART1_TX/AIN5/(HS)_PD5), R3.2, R4.2

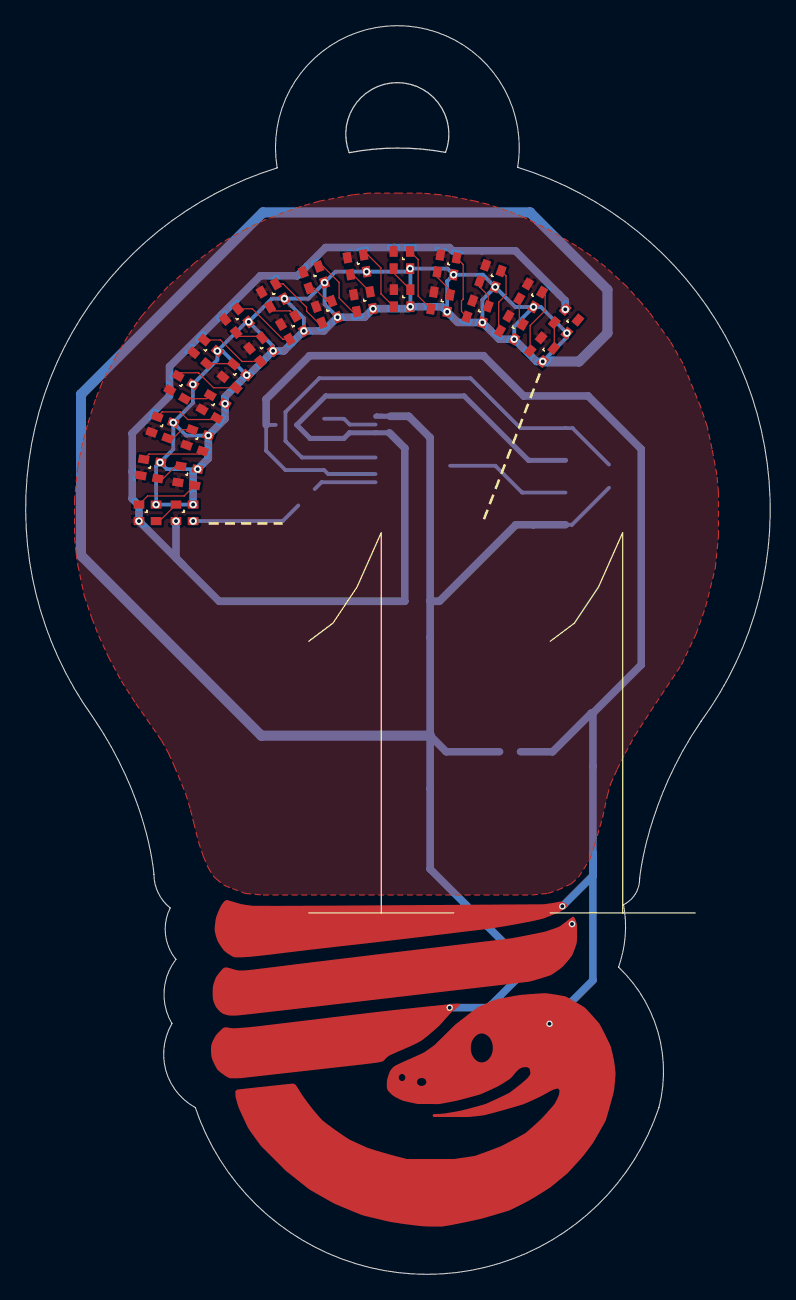
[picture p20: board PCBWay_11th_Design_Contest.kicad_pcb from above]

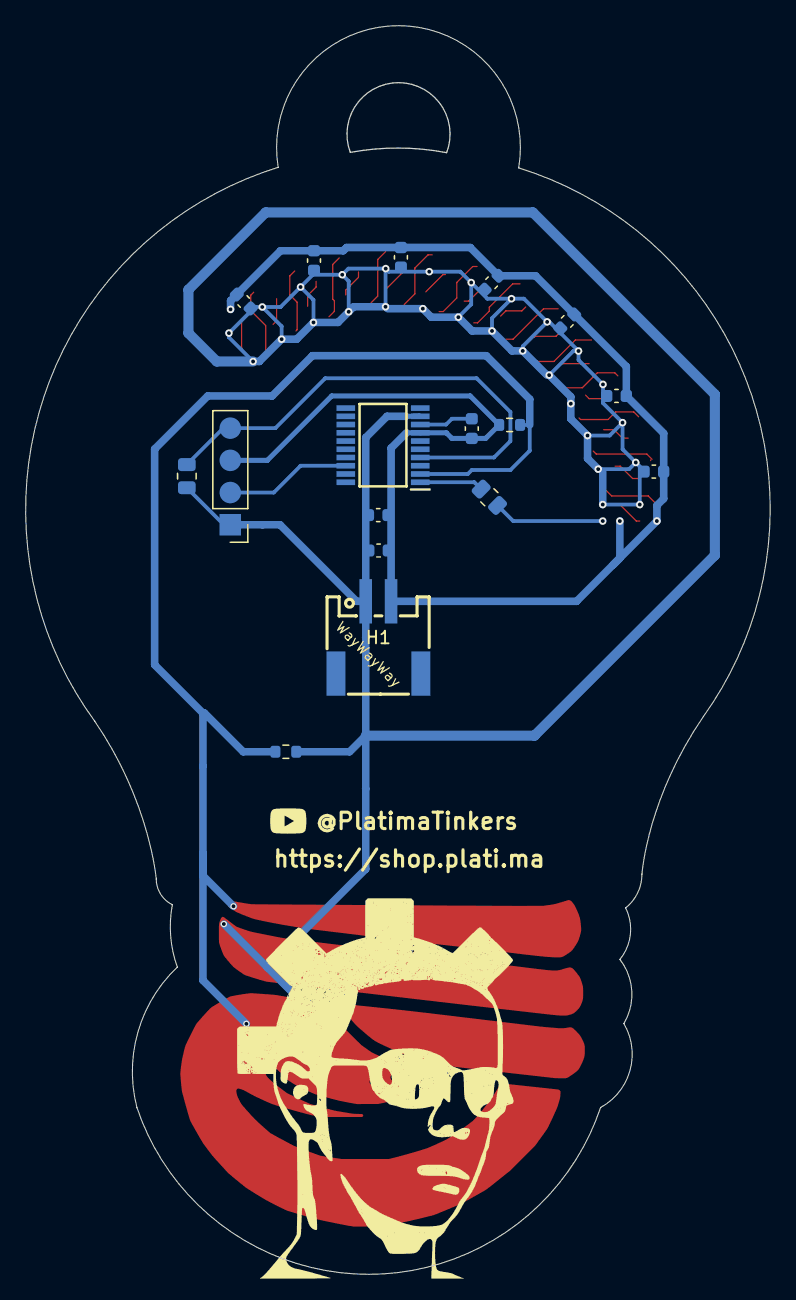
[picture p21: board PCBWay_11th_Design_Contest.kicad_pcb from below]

Board: 2 copper layers, 58.7 x 98.5 mm, 45 parts (17 on the bottom side), 35 nets.

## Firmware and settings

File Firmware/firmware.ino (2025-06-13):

/*
 * Innovation Lightbulb Badge - Touch-Activated LED Controller
 * PCBWay 11th Badge Design Contest Entry
 * 
 * Description: Interactive badge featuring touch-activated cog/gear LED animation
 *              Celebrates "11 Years of Innovation and Beyond with PCBWay"
 * 
 * Hardware: STM8S003F3 microcontroller (20-pin TSSOP)
 *           28x WS2812B LEDs arranged in 14×2 cog/gear pattern
 *           Touch sensor pads (golden snake base)
 *           LiPo battery with charging circuit
 * 
 * Author: PlatimaTinkers
 * Date: June 2025
 * License: MIT License
 * 
 * Repository: https://github.com/platima/PCBWay-11th-Design-Contest
 * Board Library: https://github.com/akashkapashia/stm8_arduino/raw/master/package_sduino_stm8_index.json
 * WS2812 Library: https://github.com/ctxz/TinyWS2812 / https://ctxz.github.io/TinyWS2812/ 
 * PCBWay Shared: https://www.pcbway.com/project/shareproject/
 * 
 * Contest Theme: "11 Years of Innovation and Beyond with PCBWay"
 * 
 * Features:
 * - Touch-activated cog/gear LED animation
 * - Low power battery operation with sleep mode
 * - Customisable colors and patterns
 * - Cultural integration (Year of the Wood Snake 2025)
 * - Interactive badge encouraging human connection
 * - Demonstrates PCBWay's precision manufacturing capabilities
 */

#include <Arduino.h>
#include "ws2812.h"

// Adjust total number of LEDs in your strip
#define N_LEDS          32
#define DATA_PORT_BASE  GPIOD_BaseAddress
#define DATA_PIN        {GPIO_PIN_4}
#define RESET_TIME      30
#define COLOR_ORDER     grb

// Input settings
#define SNAKE_PORT      GPIOD
#define SNAKE_PIN       GPIO_PIN_5

// Animation settings
#define ANIMATION_DELAY 200     // Animation delay in milliseconds
#define TOOTH_SIZE      4       // Number of LEDs per tooth
#define TOOTH_GAP       4       // Gap between teeth
#define SHIFT_AMOUNT    2       // How many LEDs to shift by each step
#define BRIGHTNESS      64      // Half brightness (0-255)

// Voltage values for touch
#define TOUCH_THRESHOLD_MV 800  // 500mV threshold for reliable touch detection
#define ADC_VREF_MV     4100    // 3.3V reference voltage in millivolts
#define ADC_RESOLUTION  1023    // 10-bit ADC (2^10 - 1)
#define ADC_TO_MV_FACTOR (ADC_VREF_MV / ADC_RESOLUTION)  // ~4mV per ADC count

// Animation modes for different occasions
#define MODE_RAINBOW    0     // Rainbow color cycling
#define MODE_PCBWAY     1     // PCBWay green theme  
#define MODE_FORTUNE    2     // Red for good fortune
#define MODE_AUSTRALIA  3     // National colors
#define MODE_WHITE      4     // Just plain white
#define MODE_COUNT      5     // Number of modes, always top number
#define MODE_CHANGE_MS  10000 // 10 seconds
#define MODE_DEFAULT    MODE_RAINBOW

// LED Globals
uint8_t led_pin[] = DATA_PIN;
ws2812_rgb leds[N_LEDS]; 
ws2812 ws2812_dev;
uint8_t current_mode = MODE_DEFAULT;

// On to the functions
void STM8_Init_16MHz_Clock() {
  CLK_DeInit();
  CLK_HSICmd(ENABLE);
  CLK_HSECmd(DISABLE);
  CLK_LSICmd(DISABLE);
  CLK_SYSCLKConfig(CLK_PRESCALER_CPUDIV1);
  CLK_SYSCLKConfig(CLK_PRESCALER_HSIDIV1);
  CLK_ClockSwitchConfig(CLK_SWITCHMODE_AUTO, CLK_SOURCE_HSI, DISABLE, CLK_CURRENTCLOCKSTATE_DISABLE);
}

void ADC_Init() {
  // Enable ADC clock
  CLK_PeripheralClockConfig(CLK_PERIPHERAL_ADC, ENABLE);
  
  // Configure PD5 as analog input
  GPIO_Init(SNAKE_PORT, SNAKE_PIN, GPIO_MODE_IN_FL_NO_IT);
  
  // ADC configuration
  ADC1_DeInit();
  ADC1_Init(ADC1_CONVERSIONMODE_CONTINUOUS, 
            ADC1_CHANNEL_5,
            ADC1_PRESSEL_FCPU_D18, 
            ADC1_EXTTRIG_TIM, 
            DISABLE, 
            ADC1_ALIGN_RIGHT, 
            ADC1_SCHMITTTRIG_ALL, 
            DISABLE);
  
  ADC1_Cmd(ENABLE);
}

uint16_t ADC_ReadValue() {
  unsigned int result = 0;

  // Start conversion
  ADC1_StartConversion();
  
  // Wait for conversion to complete
  while (ADC1_GetFlagStatus(ADC1_FLAG_EOC) == RESET);
  
  // Read the result
  result = ADC1_GetConversionValue();

  // Clear the conversion flag
  ADC1_ClearFlag(ADC1_FLAG_EOC);

  // Return the value
  return result;
}

bool CheckTouchSensor() {
  uint16_t sensorValue = ADC_ReadValue();
  return ((sensorValue * ADC_TO_MV_FACTOR) > TOUCH_THRESHOLD_MV);
}

void WS2812_LEDs_Write(ws2812 *ws2812_dev) {
  ws2812_prep_tx(ws2812_dev);
  ws2812_tx(ws2812_dev, leds, N_LEDS);
  ws2812_close_tx(ws2812_dev);
}

// Clear all LEDs (turn off)
void WS2812_LEDs_Clear() {
  for (unsigned int i = 0; i < N_LEDS; i++) {
    leds[i].r = 0;
    leds[i].g = 0;
    leds[i].b = 0;              
  }
}

// Set LED color based on current animation mode and index
void WS2812_LEDs_SetColor(int index, uint8_t mode) {
  if (index < 0 || index >= N_LEDS) return;
  
  switch(mode) {
    case MODE_RAINBOW: {
      // Rainbow mode - cycle through colors based on position
      int color_section = (index * 6) / N_LEDS;
      int fade = ((index * 6) % N_LEDS) * 255 / N_LEDS;
      
      switch(color_section) {
        case 0: // Red to Yellow
          leds[index].r = BRIGHTNESS;
          leds[index].g = (fade * BRIGHTNESS) / 255;
          leds[index].b = 0;
          break;
        case 1: // Yellow to Green  
          leds[index].r = ((255 - fade) * BRIGHTNESS) / 255;
          leds[index].g = BRIGHTNESS;
          leds[index].b = 0;
          break;
        case 2: // Green to Cyan
          leds[index].r = 0;
          leds[index].g = BRIGHTNESS;
          leds[index].b = (fade * BRIGHTNESS) / 255;
          break;
        case 3: // Cyan to Blue
          leds[index].r = 0;
          leds[index].g = ((255 - fade) * BRIGHTNESS) / 255;
          leds[index].b = BRIGHTNESS;
          break;
        case 4: // Blue to Magenta
          leds[index].r = (fade * BRIGHTNESS) / 255;
          leds[index].g = 0;
          leds[index].b = BRIGHTNESS;
          break;
        default: // Magenta to Red
          leds[index].r = BRIGHTNESS;
          leds[index].g = 0;
          leds[index].b = ((255 - fade) * BRIGHTNESS) / 255;
          break;
      }
      break;
    }
    
    case MODE_PCBWAY:
      // PCBWay green theme - RGB(17, 167, 59) scaled to brightness
      leds[index].r = (17 * BRIGHTNESS) / 255;   // Red component scaled
      leds[index].g = (167 * BRIGHTNESS) / 255;  // Green component scaled  
      leds[index].b = (59 * BRIGHTNESS) / 255;   // Blue component scaled
      break;
      
    case MODE_FORTUNE:
      // Red for good fortune and joy
      leds[index].r = BRIGHTNESS;
      leds[index].g = 0;
      leds[index].b = 0;
      break;
      
    case MODE_AUSTRALIA:
      // Green and gold for Australia (customizable)
      if ((index / TOOTH_SIZE) % 2 == 0) {
        // Gold
        leds[index].r = BRIGHTNESS;
        leds[index].g = BRIGHTNESS * 3/4;
        leds[index].b = 0;
      } else {
        // Green
        leds[index].r = 0;
        leds[index].g = BRIGHTNESS;
        leds[index].b = 0;
      }
      break;
      
    case MODE_WHITE:
      // Red for good fortune and joy
      leds[index].r = BRIGHTNESS;
      leds[index].g = BRIGHTNESS;
      leds[index].b = BRIGHTNESS;
      break;
  }
}

void setup() {
  // Setup the clock
  STM8_Init_16MHz_Clock();

  // Disable unnecessary peripherals
  CLK_PeripheralClockConfig(CLK_PERIPHERAL_SPI, DISABLE);
  CLK_PeripheralClockConfig(CLK_PERIPHERAL_I2C, DISABLE);
  CLK_PeripheralClockConfig(CLK_PERIPHERAL_UART1, DISABLE);
  CLK_PeripheralClockConfig(CLK_PERIPHERAL_UART2, DISABLE);
  CLK_PeripheralClockConfig(CLK_PERIPHERAL_TIMER1, DISABLE);
  CLK_PeripheralClockConfig(CLK_PERIPHERAL_TIMER2, DISABLE);
  CLK_PeripheralClockConfig(CLK_PERIPHERAL_TIMER3, DISABLE);
  UART1_DeInit();

  // ADC Init
  ADC_Init();

  // LEDs setup
  ws2812_cfg cfg;
  cfg.pins          = led_pin;
  cfg.rst_time_us   = RESET_TIME;
  cfg.order         = COLOR_ORDER;
  cfg.n_dev         = sizeof(led_pin);
  cfg.port_baseaddr = DATA_PORT_BASE;
  ws2812_config(&ws2812_dev, &cfg);
  
  // Initial clear of LEDs
  WS2812_LEDs_Clear();
  WS2812_LEDs_Write(&ws2812_dev);
}

void loop() {
  static uint8_t position = 0;
  static uint32_t last_mode_change = 0;
  
  // Check touch sensor
  if (! CheckTouchSensor()) {
    // Touch not detected - clear LEDs
    WS2812_LEDs_Clear();
    WS2812_LEDs_Write(&ws2812_dev);
    
    while (! CheckTouchSensor()) {
      // Small delay to prevent excessive checking
      delay(150);
    }
    
    // Touch detected
    // Reset animation position and mode change
    position = 0;
    last_mode_change = millis();
    current_mode = MODE_DEFAULT;
  }
  
  // Touch is active - run normal animation
  // Clear all LEDs
  WS2812_LEDs_Clear();
  
  // Light up every TOOTH_SIZE + TOOTH_GAP LEDs, starting at current position
  for (int tooth = 0; tooth < (N_LEDS / (TOOTH_SIZE + TOOTH_GAP)) + 1; tooth++) {
    // Calculate starting LED for this tooth
    int startLed = position + tooth * (TOOTH_SIZE + TOOTH_GAP);
    
    // Light up TOOTH_SIZE LEDs for this tooth
    for (int i = 0; i < TOOTH_SIZE; i++) {
      int ledIndex = (startLed + i) % N_LEDS;  // Wrap around if needed
      
      // Do the LED thing!
      WS2812_LEDs_SetColor(ledIndex, current_mode);
    }
  }
  
  // Update the LEDs
  WS2812_LEDs_Write(&ws2812_dev);
  
  // Increment position for next cycle
  position = (position + SHIFT_AMOUNT) % (TOOTH_SIZE + TOOTH_GAP);

  // Change animation mode occasionally for variety
  if (millis() - last_mode_change > MODE_CHANGE_MS) {  // Change every 30 seconds of cumulative use
    current_mode = (current_mode + 1) % MODE_COUNT;
    last_mode_change = millis();
  }
  
  // Wait for specified time
  delay(ANIMATION_DELAY);
}

// See: https://community.st.com/s/question/0D50X00009XkhigSAB/what-is-the-purpose-of-define-usefullassert
#ifdef USE_FULL_ASSERT
void assert_failed(uint8_t* file, uint32_t line) { 
  while (1) {}
}
#endif

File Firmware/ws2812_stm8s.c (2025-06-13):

/*
 * Copyright (C) 2022  Patrick Pedersen

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
 */

/**
 * @file ws2812_stm8s.c
 * @author Patrick Pedersen
 * @date 2022-10-26
 * 
 * @brief Driver code for STM8S chips.
 * 
 * The following file holds the Tiny-WS2812 library code to drive 
 * WS2812 devices on STM8S chips.
 */

#define WS2812_TARGET_PLATFORM_STM8S // 2025-05-21 Platima: Added due to how Arduino compiles - not defined at build time
#ifdef WS2812_TARGET_PLATFORM_STM8S

#include <stm8s.h>
#include <stddef.h>
#include <stdbool.h>

#include "ws2812_common.h" // 2025-05-21 Platima: Changed to "";s due to local include
#include "ws2812_stm8s.h" // 2025-05-21 Platima: As above

// Ensure that CPU clock runs at 16 MHz
#if F_CPU != 16000000UL
#error "F_CPU must be 16MHz!"
#endif

// Helper constants for time critical stuff
#define TICKS_PER_LOOP 2					///< Number of CPU ticks per loop in delay_us function
#define LOOPS_PER_US (F_CPU / TICKS_PER_LOOP / 1000000UL)	///< Number for loops required for 1 us to pass
#define LDW_OVERHEAD 2						///< Number of CPU ticks for the LDW instruction

// GPIO masks to quickly drive the WS2812 data line
volatile static uint16_t _port_odr_addr;	///< Address of the ODR register
volatile static uint8_t _mask_hi;		///< Mask for high state
volatile static uint8_t _mask_lo;		///< Mask for low state

static bool _prep = false;			///< Flag to indicate if the driver is prepared

// Decrementing coutner for the delay_us function
volatile static uint16_t _us_loops_remaining;

/**
 * @brief Halts the program for a given ammount of microseconds.
 * 
 * The following function temporarily disables interrupts and pauses the program
 * code for a provided ammount of microseconds (max 255).
 * 
 * @param us Number of microseconds to pause for.
 * 
 * @warning This function is blocking, meaning it reserves the CPU from performing any other tasks.
 */
static void delay_us(uint8_t us)
{
	_us_loops_remaining = (us * LOOPS_PER_US) - LDW_OVERHEAD;

	__asm
		ldw x, __us_loops_remaining	// 2 Cycles
	0000$:
		decw x				// 1 Cycle
		jrne 0000$			// 1-2 Cycles

	__endasm;
}

// Refer to header for documentation
uint8_t ws2812_config(ws2812 *dev, ws2812_cfg *cfg)
{
	dev->port_baseaddr = cfg->port_baseaddr;
	dev->rst_time_us = cfg->rst_time_us;

	GPIO_TypeDef *port = (GPIO_TypeDef *)dev->port_baseaddr;

	uint8_t pin_msk = 0;

	for (uint8_t i = 0; i < cfg->n_dev; i++) {
		pin_msk |= cfg->pins[i];
		GPIO_Init(port, cfg->pins[i], GPIO_MODE_OUT_PP_LOW_FAST);
	}

	dev->maskhi = pin_msk;
	dev->masklo = ~pin_msk;

	_ws2812_get_rgbmap(&dev->rgbmap, cfg->order);

	return 0;
}

// Refer to header for documentation
void ws2812_prep_tx(ws2812 *dev)
{
	if (_prep == true)
		return;

	_port_odr_addr = dev->port_baseaddr;
	_mask_hi = dev->maskhi;
	_mask_lo = dev->masklo;
	
	_prep = true;
}

// Refer to header for documentation
void ws2812_wait_rst(ws2812 *dev)
{
	if (dev->rst_time_us)
		delay_us(dev->rst_time_us);
}

/**
 * @brief Transmitts a 1 bit to the WS2812 device.
 * 
 * The following function transmits a 1 bit to the WS2812 device.
 * This is done in inline assembly to ensure that the timing is
 * kept up.
 * 
 * To transmitt a 1 bit, the data line is pulled high for 700ns,
 * then pulled low for 600ns, each allowing for a 150ns margin.
 * 
 * Since we are running at 16 MHz, that would approximately be
 * 11 - 12 CPU ticks for the high state and 9 - 10 CPU ticks for the low
 * state. The "correct" ammount has been brute forced through trail and error.
 * 
 * The instructions bellow toggle the data line and waits approximately
 * the required time for the high and low state as provided by the
 * datasheet.
 * 
 * To prevent timing inconsistencies due to pipelining, the function
 * must not be made inline, as the function call flushes the pipeline.
 * 
 * Due to the 150ns margin, the function can be looped thus thankfully
 * allowing us to abstract the rest in c code.
 * 
 * @warning This function is blocking, meaning it reserves the CPU from performing any other tasks.
 */
static void ws2812_tx_bit_1() // DO NOT INLINE TO PREVENT PIPELINING
{
	__asm
		ldw x, __port_odr_addr	// Load address of ODR register into X - 2 Cycles
		ld a, (x)		// Load content of ODR register into A - 1 Cycle
		or a, __mask_hi		// Set data line pin high using the pin mask - 1 Cycle
		ld (x), a		// Apply changes to ODR register - 1 Cycle
		nop			// Waste cycles until ~700ns have passed (nops are 1 cycle each)
		nop
		nop
		nop
		nop
		nop
		nop
		nop
		and a, __mask_lo	// Set data line pin low using the pin mask - 1 Cycle
		ld (x), a		// Apply changes to ODR register - 1 Cycle
		nop			// Waste cycles until ~600ns have passed (nops are 1 cycle each)
		nop
		nop
		nop
		nop
		nop
		nop
	__endasm;
}

/**
 * @brief Transmitts a 1 bit to the WS2812 device.
 * 
 * The following function transmits a 0 bit to the WS2812 device.
 * This is done in inline assembly to ensure that the timing is
 * kept up.
 * 
 * To transmitt a 0 bit, the data line is pulled high for 350ns,
 * then pulled low for 800ns, each allowing for a 150ns margin.
 * 
 * Since we are running at 16 MHz, that would approximately be
 * 5 - 6 CPU ticks for the high state and 12 - 13 CPU ticks for the low
 * state. The "correct" ammount has been brute forced through trail and error.
 * 
 * The instructions bellow toggle the data line and waits approximately
 * the required time for the high and low state as provided by the
 * datasheet.
 * 
 * To prevent timing inconsistencies due to pipelining, the function
 * must not be made inline, as the function call flushes the pipeline.
 * 
 * Due to the 150ns margin, the function can be looped thus thankfully
 * allowing us to abstract the rest in c code.
 * 
 * @warning This function is blocking, meaning it reserves the CPU from performing any other tasks.
 */
static void ws2812_tx_bit_0() // DO NOT INLINE TO PREVENT PIPELINING
{
	__asm
		ldw x, __port_odr_addr
		ld a, (x)
		or a, __mask_hi
		ld (x), a
		nop
		nop
		and a, __mask_lo
		ld (x), a
		nop
		nop
		nop
		nop
		nop
		nop
		nop
		nop
		nop
		nop
	__endasm;
}

/**
 * @brief Transmits a byte of data to the WS2812 device.
 * 
 * The following function transmits a single byte of data to the WS2812 device.
 * This is done by looping through the bits of the byte and calling the
 * appropriate ws2812_tx_bit_* function.
 * 
 * @param byte The byte to be transmitted.
 */
static inline void ws2812_tx_byte(uint8_t byte)
{
	for (uint8_t i = 0; i < 8; i++)
	{
		disableInterrupts();
		if (byte & 0b10000000) // Tests every bit in the byte
			ws2812_tx_bit_1();
		else
			ws2812_tx_bit_0();
		enableInterrupts();
		byte <<= 1;
	}
}

// Refer to header for documentation
void ws2812_tx(ws2812 *dev, ws2812_rgb *leds, size_t n_leds)
{
        for (size_t i = 0; i < n_leds; i++) {
                for (uint8_t j = 0; j < sizeof(dev->rgbmap); j++) {
                        uint8_t *pxl = (uint8_t *) &(leds[i]);
                        ws2812_tx_byte(pxl[dev->rgbmap[j]]);
                }
        }
}
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

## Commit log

2025-06-13 Add files, rneames
    [BOM.csv]
2025-06-13 Added KiCad files
    [AT42QT1010-TSHR.stp, BAT-HLD-003-SMT.stp, BAT-SMD_MY-2032-12.step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]
2025-06-13 Update BOM and Centroid
    [BOM.csv]
2025-06-13 Add datasheets & schematic

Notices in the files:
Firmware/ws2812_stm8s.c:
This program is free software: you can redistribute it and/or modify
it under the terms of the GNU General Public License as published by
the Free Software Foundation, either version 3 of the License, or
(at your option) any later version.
